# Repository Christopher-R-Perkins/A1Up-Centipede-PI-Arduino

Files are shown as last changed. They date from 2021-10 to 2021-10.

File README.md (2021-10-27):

## Centipede Arcade1Up Arduino Interface
### Goal of this project
First generation Arcade1Up uses proprietary circuit boards to interface with the game's circuit board through a 40 pin IDC cable. The goal of this project is to create an interface for any PC that can be hooked directly to their proprietary circuit board via the IDC cable and interpret the output as a joystick or mouse.

I chose the Arduino Leonardo for it's ability to emulate USB devices and the ease of creating shields with it's form factor. 

This is an update for the direct connection to the raspberry pi I used to use. Python proved too slow for my purposes and I was always worried about stealing cpu cycles that could of been better used for game performance. Moving this to a microprocessor fixed everything.

### IDC 40 Pinout
| Pin | Function |
|--|--|
| 1 | P1 Start |
| 2 | Uart Pin 2 |
| 3 | P2 Start |
| 4 | Uart pin 1 |
| 5 | A Button |
| 6 | B Button |
| 7 | C Button |
| 13 | UART 5V |
| 14 | UART GND |
| 18 | GND |
| 35 | Pwr Switch |
| 37 | Vol A(up) |
| 38 | Vol B(down) |
| 39 | Speaker |
| 40 | Speaker |

The UART on this is 5v, so we can directly connect it to our Arduino Leonardo. Every button needs it's own channel as well. 

### UART encoding
I used a logic analyzer to decode what was going on via the serial communication. Looking at the rate of pulses I found out it was 115200 speed. Counting the pulses based on that speed I found out it was 7n1.

The game board does not poll the controller board, the trackball just sends the data as you move the ball. It sends 4 bytes of data for every move like this:

    7F XX YY ZZ
XX and YY are the X and Y axis of the trackball and ZZ is in use when a spinner is installed(select cabinets). The values can be 7E(-1), 00(0), 01(1).

### Putting it together
Knowing how the UART works and what pins go where, I prototyped my device. Since I didnt need to convert voltages, it was simple to just make the traces go directly to the IDC 40 connector.

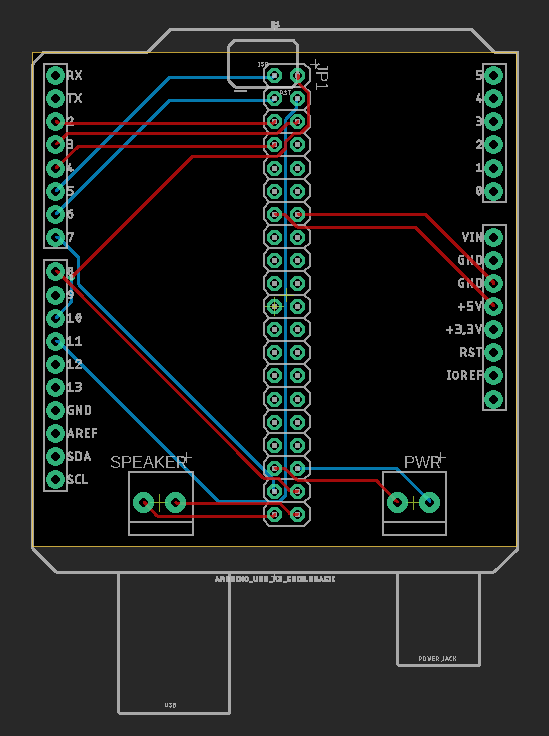
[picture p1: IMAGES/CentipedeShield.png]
View of Circuit Board Design


Since I got the circuit working and programmed a solution, all I needed to do was fabricate a board and solder it. 

I decided to keep my automatic swapping by communicating via the serial port emulated by the USB. 

First we gotta make our device readable, so that we can send messages via BASH. Add this line to your /etc/rc.local, so that we can use it later in the runcommand-onstart/onend.sh scripts.
 `chmod o+rw /dev/ttyACM0`
You should now be able to put in the runncommand scripts and be good.

You'll find the fabrication files and the source code to this in this repository.

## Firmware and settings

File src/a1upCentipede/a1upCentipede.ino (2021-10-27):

#define _SS_MAX_RX_BUFF 64
#include <SoftwareSerial7N1.h>
#include <HID-Project.h>

//                  a      b      c      p1     p2     vup    vdown  up     right  down   left
byte checks[] =    {false, false, false, false, false, false, false, false, false, false, false};
const int pins[] = {2    , 3    , 4    , 5    , 6    , 7    , 8};
// We don't use 0 and 1 as we'll be using the uart to communicate with pi.
byte mode = 'j';
// 'j' Joypad, 't' trackball, 'm' SCUMMVM


unsigned long joypad_time = 0;
int x = 0;
int y = 0;

const uint8_t keys[] = {KEY_A, KEY_S, KEY_D, KEY_ENTER, KEY_DELETE};

SoftwareSerial7N1 trackballSerial(10,11);

unsigned long exit_time = 0;
bool check_exit = false;

void setup() {
    // Five Buttons
    pinMode(2, INPUT_PULLUP);
    pinMode(3, INPUT_PULLUP);
    pinMode(4, INPUT_PULLUP);
    pinMode(5, INPUT_PULLUP);
    pinMode(6, INPUT_PULLUP);
    // Volume Switch
    pinMode(7, INPUT_PULLUP);
    pinMode(8, INPUT_PULLUP);
    // UART
    pinMode(10, INPUT);
    pinMode(11, OUTPUT);
    
    Keyboard.begin();
    Mouse.begin();
    Consumer.begin();
    
    Serial.begin(115200);
    //while(!Serial);
    
    trackballSerial.begin(115200);
    trackballSerial.listen();
}

void input_outputter(int check_index, byte device, uint8_t keycode) { // my way to debounce without tracking time
  switch(checks[check_index]) {
  case 0: // Unpressed
    if (digitalRead(pins[check_index]) == LOW) checks[check_index]++;
      break;
  case 1:  // pressed for 1/120th of a second
    if (digitalRead(pins[check_index]) == LOW) {
      checks[check_index]++;
      if (device == 'k') Keyboard.press((KeyboardKeycode)keycode);
      else if (device == 'm') Mouse.press(keycode);
      else Consumer.press(keycode);
    } else {
      checks[check_index]--;
    }
    break;
  case 2: // pressed for 1/60th and above.
    if (digitalRead(pins[check_index]) == HIGH) checks[check_index]++;
    break;
  case 3: // unpressed for 1/20th of a second
    if (digitalRead(pins[check_index]) == LOW) checks[check_index]--;
    else {
      checks[check_index] = 0;
      if (device == 'k') Keyboard.release((KeyboardKeycode)keycode);
      else if (device == 'm') Mouse.release(keycode);
      else Consumer.release(keycode);
    }
    break;
  default:
    break;
  }
}

int new_mode = 'j';

void loop() {
  unsigned long currentMicros = micros();
  
  // We need to be able to change the mode via serial port
  while(Serial.available() > 0) {
    new_mode = Serial.read();
  }
  if (new_mode != mode) {
    mode = new_mode;
    
    // Since bindings might change we got clear our outputs
    Mouse.releaseAll();
    Keyboard.releaseAll();
    x = 0;
    y = 0;
    for(int i = 0; i < 11; i++) checks[i] = 0;
    
    // We may have exited to change modes
    check_exit = false;
  }
    
  int vertical = 0;
  int horizontal = 0;
    
  int bytesToRead = trackballSerial.available();
  for(int i = 0; i < bytesToRead-3; i++) {
    if (trackballSerial.read() == 127) {
      byte trackball[] = {0, 0, 0};
      for(int j = 0; j<3; j++) {
        trackball[j] = trackballSerial.read(); 
        i++;
      }
      horizontal += dataConvert(trackball[0]);
      vertical += dataConvert(trackball[1]);
    }
  }

  // First Joystick/Mouse Movement.
  switch(mode){
    case 'j':
      // Basically we only do joypad stuff 50 times a second!
      if (millis() - joypad_time < 20) {
        x+= horizontal;
        y+= vertical;
        break;
      }
      
      if (y < -2) {
        if (!checks[7]) {
          checks[7] = true;
          Keyboard.press(KEY_UP);
        }
      } else if (checks[7]) {
        checks[7] = false;
        Keyboard.release(KEY_UP);
      }
      if (y > 2) {
        if (!checks[9]) {
          checks[9] = true;
          Keyboard.press(KEY_DOWN);
        }
      } else if (checks[9]) {
        checks[9] = false;
        Keyboard.release(KEY_DOWN);
      }

      if (x > 8) {
        if (!checks[8]) {
          checks[8] = true;
          Keyboard.press(KEY_RIGHT);
        }
      } else if (checks[8]) {
        checks[8] = false;
        Keyboard.release(KEY_RIGHT);
      }
      if (x < -8) {
        if (!checks[10]) {
          checks[10] = true;
          Keyboard.press(KEY_LEFT);
        }
      } else if (checks[10]) {
        checks[10] = false;
        Keyboard.release(KEY_LEFT);
      }
      x = 0;
      y = 0;
      joypad_time = millis();
      break;
    case 'm':
      if (abs(horizontal) > 4) horizontal = horizontal * 2;
      else if (abs(horizontal) > 2) horizontal = horizontal * 3/2;
      if (abs(vertical)  > 4) vertical = vertical * 2;
      else if (abs(vertical) > 2) vertical = vertical * 3/2;
    case 't':
      Mouse.move((char)horizontal, (char)vertical, 0);
      break;
    default:
      break;
  }

    // now we deal with buttons:)
    switch(mode) {
      case 'j':
      case 't':
        for(int i = 0; i < 5; i++) input_outputter(i,'k',keys[i]);
        if (checks[3] > 1) {
          if (!check_exit) {
            check_exit = true;
            exit_time = millis();
          }
          if ((millis()-exit_time >= 5000)) {
            Keyboard.write(KEY_ESC);
            new_mode = 'j';
          }
        } else {
          check_exit = false;
        }
        break;
      case 'm':
        input_outputter(0,'m',MOUSE_LEFT);
        input_outputter(1,'m',MOUSE_RIGHT);
        input_outputter(2,'k',KEY_ESC);
        input_outputter(3,'k',KEY_F5);
        input_outputter(4,'k',KEY_F7);
        
        if (checks[3] > 1) {
          if (!check_exit) {
            check_exit = true;
            exit_time = millis();
          }
          if (millis()-exit_time >= 5000) {
            Keyboard.press(KEY_LEFT_CTRL);
            Keyboard.write(KEY_Q);
            Keyboard.release(KEY_LEFT_CTRL);
            new_mode = 'j';
          }
        } else {
          check_exit = false;
        }
        break;
      default:
        break;
    }

    // Finally let's fix volume!
    input_outputter(5,'c',MEDIA_VOLUME_DOWN);
    input_outputter(6,'c',MEDIA_VOLUME_UP);
}

int dataConvert(byte b) 
{
    if (b == 126)
      return -1;
    if (b == 1) return 1;
    return 0;
}

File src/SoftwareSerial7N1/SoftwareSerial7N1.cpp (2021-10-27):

/*
SoftwareSerial7N1.cpp (formerly SoftwareSerial.cpp, formerly NewSoftSerial.cpp) - 
Edited for 7n1 and a bigger buffer
Multi-instance software serial library for Arduino/Wiring
-- Interrupt-driven receive and other improvements by ladyada
   (http://ladyada.net)
-- Tuning, circular buffer, derivation from class Print/Stream,
   multi-instance support, porting to 8MHz processors,
   various optimizations, PROGMEM delay tables, inverse logic and 
   direct port writing by Mikal Hart (http://www.arduiniana.org)
-- Pin change interrupt macros by Paul Stoffregen (http://www.pjrc.com)
-- 20MHz processor support by Garrett Mace (http://www.macetech.com)
-- ATmega1280/2560 support by Brett Hagman (http://www.roguerobotics.com/)

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
The latest version of SoftwareSerial.cpp can always be found at
http://arduiniana.org.
*/

// When set, _DEBUG co-opts pins 11 and 13 for debugging with an
// oscilloscope or logic analyzer.  Beware: it also slightly modifies
// the bit times, so don't rely on it too much at high baud rates
#define _DEBUG 0
#define _DEBUG_PIN1 11
#define _DEBUG_PIN2 13
// 
// Includes
// 
#include <avr/interrupt.h>
#include <avr/pgmspace.h>
#include <Arduino.h>
#include <SoftwareSerial7N1.h>
#include <util/delay_basic.h>

//
// Statics
//
SoftwareSerial7N1 *SoftwareSerial7N1::active_object = 0;
uint8_t SoftwareSerial7N1::_receive_buffer[_SS_MAX_RX_BUFF]; 
volatile uint8_t SoftwareSerial7N1::_receive_buffer_tail = 0;
volatile uint8_t SoftwareSerial7N1::_receive_buffer_head = 0;

//
// Debugging
//
// This function generates a brief pulse
// for debugging or measuring on an oscilloscope.
#if _DEBUG
inline void DebugPulse(uint8_t pin, uint8_t count)
{
  volatile uint8_t *pport = portOutputRegister(digitalPinToPort(pin));

  uint8_t val = *pport;
  while (count--)
  {
    *pport = val | digitalPinToBitMask(pin);
    *pport = val;
  }
}
#else
inline void DebugPulse(uint8_t, uint8_t) {}
#endif

//
// Private methods
//

/* static */ 
inline void SoftwareSerial7N1::tunedDelay(uint16_t delay) { 
  _delay_loop_2(delay);
}

// This function sets the current object as the "listening"
// one and returns true if it replaces another 
bool SoftwareSerial7N1::listen()
{
  if (!_rx_delay_stopbit)
    return false;

  if (active_object != this)
  {
    if (active_object)
      active_object->stopListening();

    _buffer_overflow = false;
    _receive_buffer_head = _receive_buffer_tail = 0;
    active_object = this;

    setRxIntMsk(true);
    return true;
  }

  return false;
}

// Stop listening. Returns true if we were actually listening.
bool SoftwareSerial7N1::stopListening()
{
  if (active_object == this)
  {
    setRxIntMsk(false);
    active_object = NULL;
    return true;
  }
  return false;
}

//
// The receive routine called by the interrupt handler
//
void SoftwareSerial7N1::recv()
{

#if GCC_VERSION < 40302
// Work-around for avr-gcc 4.3.0 OSX version bug
// Preserve the registers that the compiler misses
// (courtesy of Arduino forum user *etracer*)
  asm volatile(
    "push r18 \n\t"
    "push r19 \n\t"
    "push r20 \n\t"
    "push r21 \n\t"
    "push r22 \n\t"
    "push r23 \n\t"
    "push r26 \n\t"
    "push r27 \n\t"
    ::);
#endif  

  uint8_t d = 0;

  // If RX line is high, then we don't see any start bit
  // so interrupt is probably not for us
  if (_inverse_logic ? rx_pin_read() : !rx_pin_read())
  {
    // Disable further interrupts during reception, this prevents
    // triggering another interrupt directly after we return, which can
    // cause problems at higher baudrates.
    setRxIntMsk(false);

    // Wait approximately 1/2 of a bit width to "center" the sample
    tunedDelay(_rx_delay_centering);
    DebugPulse(_DEBUG_PIN2, 1);

    // Read each of the 8 bits
    for (uint8_t i=7; i > 0; --i)
    {
      tunedDelay(_rx_delay_intrabit);
      d >>= 1;
      DebugPulse(_DEBUG_PIN2, 1);
      if (rx_pin_read())
        d |= 0x40;
    }

    if (_inverse_logic)
      d = ~d;

    // if buffer full, set the overflow flag and return
    uint8_t next = (_receive_buffer_tail + 1) % _SS_MAX_RX_BUFF;
    if (next != _receive_buffer_head)
    {
      // save new data in buffer: tail points to where byte goes
      _receive_buffer[_receive_buffer_tail] = d; // save new byte
      _receive_buffer_tail = next;
    } 
    else 
    {
      DebugPulse(_DEBUG_PIN1, 1);
      _buffer_overflow = true;
    }

    // skip the stop bit
    tunedDelay(_rx_delay_stopbit);
    DebugPulse(_DEBUG_PIN1, 1);

    // Re-enable interrupts when we're sure to be inside the stop bit
    setRxIntMsk(true);

  }

#if GCC_VERSION < 40302
// Work-around for avr-gcc 4.3.0 OSX version bug
// Restore the registers that the compiler misses
  asm volatile(
    "pop r27 \n\t"
    "pop r26 \n\t"
    "pop r23 \n\t"
    "pop r22 \n\t"
    "pop r21 \n\t"
    "pop r20 \n\t"
    "pop r19 \n\t"
    "pop r18 \n\t"
    ::);
#endif
}

uint8_t SoftwareSerial7N1::rx_pin_read()
{
  return *_receivePortRegister & _receiveBitMask;
}

//
// Interrupt handling
//

/* static */
inline void SoftwareSerial7N1::handle_interrupt()
{
  if (active_object)
  {
    active_object->recv();
  }
}

#if defined(PCINT0_vect)
ISR(PCINT0_vect)
{
  SoftwareSerial7N1::handle_interrupt();
}
#endif

#if defined(PCINT1_vect)
ISR(PCINT1_vect, ISR_ALIASOF(PCINT0_vect));
#endif

#if defined(PCINT2_vect)
ISR(PCINT2_vect, ISR_ALIASOF(PCINT0_vect));
#endif

#if defined(PCINT3_vect)
ISR(PCINT3_vect, ISR_ALIASOF(PCINT0_vect));
#endif

//
// Constructor
//
SoftwareSerial7N1::SoftwareSerial7N1(uint8_t receivePin, uint8_t transmitPin, bool inverse_logic /* = false */) : 
  _rx_delay_centering(0),
  _rx_delay_intrabit(0),
  _rx_delay_stopbit(0),
  _tx_delay(0),
  _buffer_overflow(false),
  _inverse_logic(inverse_logic)
{
  setTX(transmitPin);
  setRX(receivePin);
}

//
// Destructor
//
SoftwareSerial7N1::~SoftwareSerial7N1()
{
  end();
}

void SoftwareSerial7N1::setTX(uint8_t tx)
{
  // First write, then set output. If we do this the other way around,
  // the pin would be output low for a short while before switching to
  // output high. Now, it is input with pullup for a short while, which
  // is fine. With inverse logic, either order is fine.
  digitalWrite(tx, _inverse_logic ? LOW : HIGH);
  pinMode(tx, OUTPUT);
  _transmitBitMask = digitalPinToBitMask(tx);
  uint8_t port = digitalPinToPort(tx);
  _transmitPortRegister = portOutputRegister(port);
}

void SoftwareSerial7N1::setRX(uint8_t rx)
{
  pinMode(rx, INPUT);
  if (!_inverse_logic)
    digitalWrite(rx, HIGH);  // pullup for normal logic!
  _receivePin = rx;
  _receiveBitMask = digitalPinToBitMask(rx);
  uint8_t port = digitalPinToPort(rx);
  _receivePortRegister = portInputRegister(port);
}

uint16_t SoftwareSerial7N1::subtract_cap(uint16_t num, uint16_t sub) {
  if (num > sub)
    return num - sub;
  else
    return 1;
}

//
// Public methods
//
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
